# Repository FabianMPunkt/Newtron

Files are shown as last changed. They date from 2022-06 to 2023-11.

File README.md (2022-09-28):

# Newtron

This little project is made to read the USBSerial output of one these ["TesT"-devices](https://www.test-gmbh.com/de/produkte/pruefmaschinen/einfache-pruefrahmen/modell-105/).
It will process the readings, turn them all into positive values and save the highest value.

With the press of a button the highest value will the be sent to the computer using the "Keyboard.h" library.

The TesT-device trannsmits all the values over its USBSerial Port in a single line as seen in [these readings](misc/OG_readings.txt).
GitHub's formatting doen't disply this correctly though. All the values are in-fact separated by a ""

A detailed build guide & more info can be found in the [Wiki](https://github.com/FabianMPunkt/Newtron/wiki).

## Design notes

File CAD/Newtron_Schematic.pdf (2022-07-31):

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
RX1/CS1/CRX2

0
TX1/MISO1/CTX2

1
OUT2

2
LRCLK2

3
BCLK2

4
IN2

5
OUT1D

6
RX2/OUT1A

7
TX2/IN1

8
OUT1C

9
CS/MQSR 10
MOSI/CTX1 11
MISO/MQSL 12 | SCK | 13 A0/TX3/S/PDIF OUT | 14 A1/RX3/S/PDIF IN | 15 A2/RX4/SCL1 | 16 A3/TX4/SDA1 | 17 A4/SDA | 18 A5/SCL | 19 A6/TX5/LRCLK1 | 20 A7/RX5/BCLK1 | 21 A8/CTX1 | 22 A9/CRX1/MCLK1 | 23

A10/TX6/SCL2 24
A11/RX6/SDA2 25
A12/MOSI1 26
A13/SCK1 27
RX7 28
TX7 29
CRX3 30
CTX3 31
OUT1B 32 | MCLK2 | 33 RX8 | 34 TX8 | 35 CS | 36 CS | 37 A14/CS1/IN1 | 38 A15/MISO1/OUT1A | 39 A16 | 40 A17 | 41 GND | G_4 3.3V 3V_0
3.3V | 3V_1 GND | G_5 Vin | 5V GND G_2
GND | G_3 R- | RX_N R+ | RX_P T- TX_N
T+ TX_P
LED LED | GND G_1 GND G_0 | USB_D⁻ D⁻ USB_D⁺ D⁺ GND G Vhost Vhost 3.3V 3V VBAT VBAT PROGRAM P ON/OFF O | USB_IN_D⁺ IN_D⁺ USB_IN_D⁻ IN_D-

U1
Teensy 4.1

Vcc

1

GND

2

SCL

3

SDA

4 5 5 6 6 7 7 8 8 9 9 10 10 11 11 12 12 13 13 14 14 15 15 16 16 17 17 18 18 19 19 20 20 21 21 22 22 23 23 24 24 25 25 26 26 27 27 28 28 29 29 30 30 31 31 32 32 33 33 34 34 35 35 36 36

# DISPLAY LCD 1602

LCD 1602 WITH I2C 1 3 2 4

SW1

Button | VCC VCC D⁻ D⁻ D⁺ D⁺ GND GND

X1
USB A Female 231

J1
3.5mm Jack

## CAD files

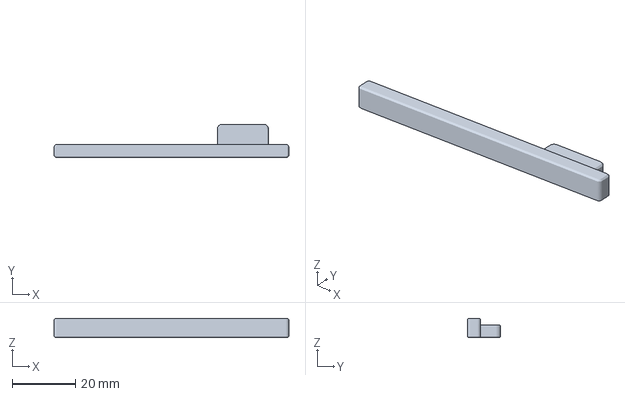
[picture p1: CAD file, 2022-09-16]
CAD/3MF/Newtron_Foot.3mf
74.2 x 10.6 x 6.06 mm

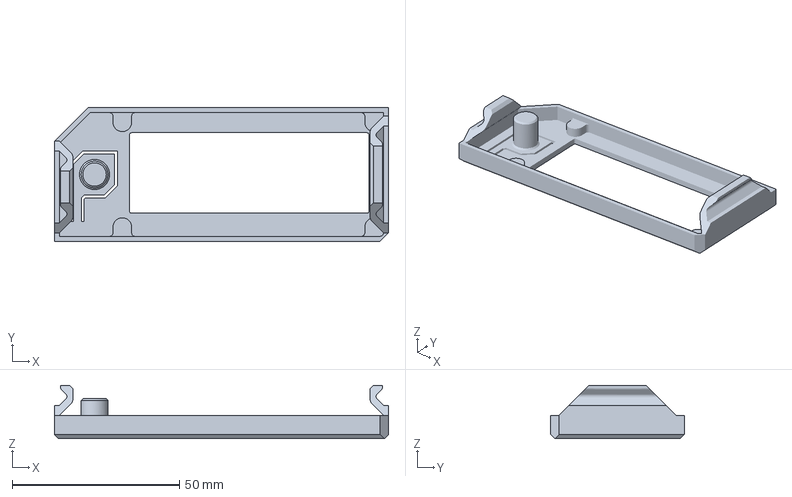
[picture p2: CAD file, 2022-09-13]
CAD/3MF/Newtron_Front.3mf
100.0 x 40.0 x 16.0 mm

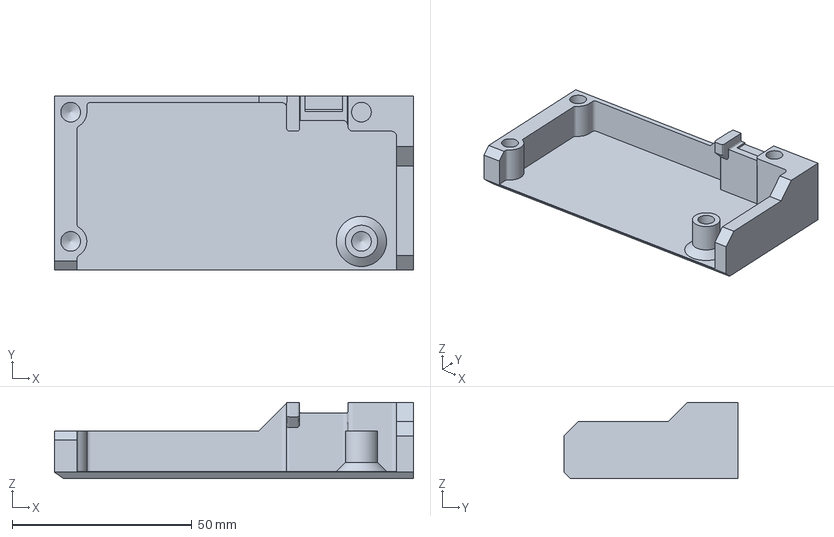
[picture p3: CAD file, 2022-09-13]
CAD/3MF/Newtron_Top.3mf
100.0 x 48.5 x 21.2 mm

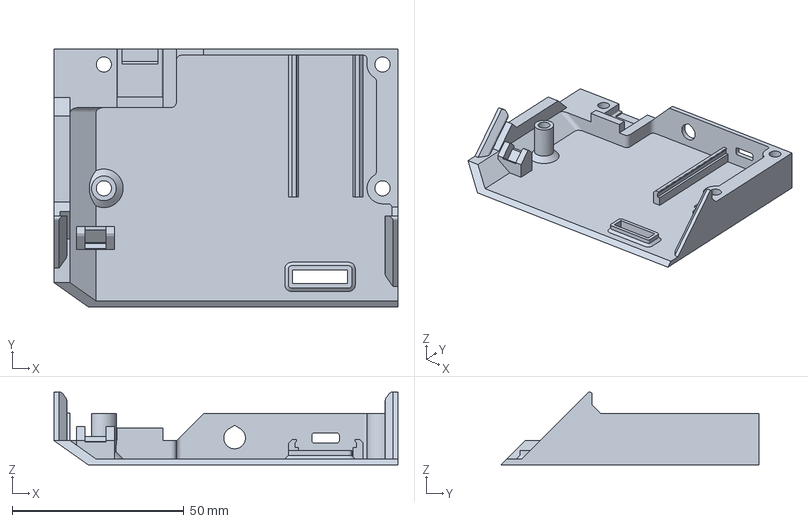
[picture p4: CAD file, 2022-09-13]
CAD/3MF/Newtron_Base.3mf
100.0 x 75.0 x 21.2 mm

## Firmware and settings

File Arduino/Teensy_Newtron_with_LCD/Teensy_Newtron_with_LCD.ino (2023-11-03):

String Version = "Newtron V1.21";

//  Teensy 4.1 + I2C LCD
//  https://github.com/FabianMPunkt/Newtron
//
//
//  USB Type: "Serial + Keyboard + Mouse + Joystick"
//  CPU Speed: 396MHz
//
//
//  This reads incoming data from Serial1, that is seperated by a "".
//  it then determines the maximum value
//  when pin3 is pulled low, it sends said value to the connected computer as if it were keyboard presses.


// Update 03.11.2023: 
// inside USBHost_t36/serial.cpp change

// // Lets try to map CDCACM devices only at device level
//  	if ((dev->bDeviceClass == 2) && (dev->bDeviceSubClass == 0)) {
//  		if (type != 0) return false;

// to

// 	// Lets try to map CDCACM devices only at device level
//	if ((dev->bDeviceClass == 2) && (dev->bDeviceSubClass == 0)) {
//
// this way it will work with newer USB-C TesT-devices.
// https://forum.pjrc.com/threads/73829-Need-help-with-USBSerial-device-not-getting-recognized-by-teensy-4-1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
//
// You may also have to uncomment "//USBHS_PORTSC1 |= USBHS_PORTSC_PFSC; // force 12 Mbit/sec"
// inside of USBHost_t36/ehci.cpp


#include "LCD_I2C.h"
LCD_I2C lcd(0x27, 16, 2);  //Defines LCD Type

#include "Keyboard.h"

#include "USBHost_t36.h"
#define USBBAUD 115200  //BAUDRADE for the Serial of the USB-Host
uint32_t baud = USBBAUD;
USBHost myusb;
USBSerial_BigBuffer userial(myusb);

USBDriver *drivers[] = { &userial };
#define CNT_DEVICES (sizeof(drivers) / sizeof(drivers[0]))
bool driver_active[CNT_DEVICES] = { false };



String integString;  //innteger part of the value
String decimString;  //decimal part of the value

float integFloat;
float decimFloat;

float finValue;
float maxValue = 0;

unsigned long millisUntilDisplayTimeout;
unsigned long displayTimeoutValue = 90000;  //timeout Value for the LCD, when inactive to prevent LCD burn-in. (using millis)

unsigned long millisUntilDataTimeout;
unsigned long dataTimeoutValue = 2000;  //timeout Value for datastream detection.

bool dataState = false;  //true if data is detected, false if not.
bool USBState = false;   //true if usb is connected, fasle if not.

const int rstPin = 11;
const int pedalPin = 8;
bool currentPedalState;
bool lastPedalState;

int animDelay = 20;

void setup() {

  bootAnimStart();  //Start sequence of the boot animation


  pinMode(pedalPin, INPUT_PULLUP);
  pinMode(rstPin, INPUT_PULLUP);

  pinMode(7, OUTPUT);  //Pin 7 and 10 are used as GND
  pinMode(10, OUTPUT);
  digitalWrite(7, LOW);
  digitalWrite(10, LOW);


  Keyboard.begin();

  Serial.begin(9600);

  Serial.println(Version);
  Serial.println("https://github.com/FabianMPunkt/Newtron");

  myusb.begin();


  bootAnimEnd();  //End sequence of the boot animation

  lcd.setCursor(0, 0);
  lcd.print("USB disconnected");  //"USB not found" message is hardcoded so it display correctly, if USB is disconnected when booting. Yes, i know it is stupid
}



void loop() {

  for (uint8_t i = 0; i < CNT_DEVICES; i++) {  //USB detection ripped from: https://github.com/PaulStoffregen/USBHost_t36/blob/master/examples/Serial/Serial.ino
    if (*drivers[i] != driver_active[i]) {

      if (driver_active[i]) {
        driver_active[i] = false;
        USBState = false;
        Serial.println("USB disconnected");
        rstMaxValue();
        lcd.clear();
        lcd.setCursor(0, 0);
        lcd.print("USB disconnected");

      }

      else {
        driver_active[i] = true;
        userial.begin(baud);
        USBState = true;
        Serial.println("USB connected");

        lcd.clear();
        rstMaxValue();

        dataState = 0;
      }
    }
  }


  while (userial.available()) {

    millisUntilDataTimeout = millis() + dataTimeoutValue;  //for datastream detection.

    if (dataState == false) {  //detects when data is coming, and runs this only once.
      lcd.setCursor(0, 0);
      lcd.print("Spitzenwert:    ");
      lcd.setCursor(0, 1);

      dataState = true;
      Serial.println("Datastream detected!");

      rstMaxValue();
    }

    integString = userial.readStringUntil(',');  //reads the value before the comma.
    integFloat = integString.toFloat();          //converts String type to Float type
    integFloat = fabsf(integFloat);              //turns all negative numbers positive


    decimString = userial.readStringUntil('');  //reads the value after the comma, until the separator ""
    decimFloat = decimString.toFloat();          //converts String type to Float type. the decimal number is now a standalone float variable.
    decimFloat = decimFloat / 10;                //devides the decimal number by 10.


    finValue = integFloat + decimFloat;  //adds integer number and decimal number.

    if (finValue > maxValue) {  //largest value gets saves as "maxValue".
      maxValue = finValue;
      displayON();  //whenever there is a new "maxValue" the LCD will turn on again.
      lcd.setCursor(0, 1);
      lcd.print(maxValue);
    }


    //    lcd.setCursor(8, 1);
    //    lcd.print("      ");
    //    lcd.setCursor(8, 1);
    //    lcd.print(finValue);


    Serial.print("fin: ");
    Serial.print(finValue);
    Serial.print(" | max: ");
    Serial.print(maxValue);
    Serial.print(" | time: ");
    Serial.print((millisUntilDisplayTimeout - millis()) / 1000);
    Serial.print(" | userial: ");
    Serial.print(userial.available());
    Serial.println();


    rstButton();

    Pedal();

    displayTimeout();
  }

  dataStreamTimeout();

  rstButton();

  displayTimeout();
}


void rstButton() {
  if (digitalRead(rstPin) == LOW) {  //reset "maxValue"
    rstMaxValue();
  }
}


void Pedal() {

  lastPedalState = currentPedalState;  //this is used to determine the falling edge when the pedal is pressed.
  currentPedalState = digitalRead(pedalPin);

  if (lastPedalState == HIGH && currentPedalState == LOW) {

    Serial.println("Pedal has been pressed");

    Keyboard.println(maxValue);
    rstMaxValue();
    delay(500);  //500ms delay so you cant accidentally press the pedal twice.
  }
}


void rstMaxValue() {
  displayON();
  maxValue = 0;
  lcd.setCursor(0, 1);
  lcd.print("                ");
  Serial.println("maxVaule has been reset");
}


void displayON() {
  millisUntilDisplayTimeout = millis() + displayTimeoutValue;

  lcd.backlight();
  lcd.display();
}


void displayTimeout() {

  if (millis() > millisUntilDisplayTimeout) {  //this turns off the LCD when the timeout is reached.
    lcd.noBacklight();
    lcd.noDisplay();
  }
}


void dataStreamTimeout() {  //if no data is coming for more than 2000ms, it will show this error.
  if (millis() > millisUntilDataTimeout) {

    if (USBState == true) {

      lcd.setCursor(0, 0);
      lcd.print("No data found!");
      lcd.setCursor(0, 1);
      lcd.print("DSI Transmission");
      dataState = false;
      Serial.println("No data found!");
    }
  }
}


void bootAnimStart() {  //fancy boot animation cus why not

  lcd.begin();
  displayON();

  lcd.setCursor(0, 0);
  lcd.print(Version.substring(0, 1));
  delay(animDelay);
  lcd.setCursor(1, 0);
  lcd.print(Version.substring(1, 2));
  delay(animDelay);
  lcd.setCursor(2, 0);
  lcd.print(Version.substring(2, 3));
  delay(animDelay);
  lcd.setCursor(3, 0);
  lcd.print(Version.substring(3, 4));
  delay(animDelay);
  lcd.setCursor(4, 0);
  lcd.print(Version.substring(4, 5));
  delay(animDelay);
  lcd.setCursor(5, 0);
  lcd.print(Version.substring(5, 6));
  delay(animDelay);
  lcd.setCursor(6, 0);
  lcd.print(Version.substring(6, 7));
  delay(animDelay);
  lcd.setCursor(7, 0);
  lcd.print(Version.substring(7, 8));
  delay(animDelay);
  lcd.setCursor(8, 0);
  lcd.print(Version.substring(8, 9));
  delay(animDelay);
  lcd.setCursor(9, 0);
  lcd.print(Version.substring(9, 10));
  delay(animDelay);
  lcd.setCursor(10, 0);
  lcd.print(Version.substring(10, 11));
  delay(animDelay);
  lcd.setCursor(11, 0);
  lcd.print(Version.substring(11, 12));
  delay(animDelay);
  lcd.setCursor(12, 0);
  lcd.print(Version.substring(12, 13));
  delay(animDelay);
}

void bootAnimEnd() {

  lcd.setCursor(0, 0);
  lcd.print("  ");
  delay(animDelay);
  lcd.print("  ");
  delay(animDelay);
  lcd.print("  ");
  delay(animDelay);
  lcd.print("  ");
  delay(animDelay);
  lcd.print("  ");
  delay(animDelay);
  lcd.print("  ");
  delay(animDelay);
}

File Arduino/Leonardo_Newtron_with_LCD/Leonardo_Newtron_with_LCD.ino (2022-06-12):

//holy shit this is working!!!!
//
//  Newtron V0.9
//  Arduino Leonardo + LCD
//  https://github.com/FabianMPunkt/Newtron
//
//
//  This reads incoming data from Serial1, that is seperated by a "".
//  it then determines the maximum value
//  when pin3 is pulled low, it sends said value to the connected computer as if it were keyboard presses.


#include <Keyboard.h>

#include <LiquidCrystal.h>

LiquidCrystal lcd(7, 8, 9, 10, 11, 12);

String integString;           //innteger part of the value
String decimString;           //decimal point of the value

float integFloat;
float decimFloat;

float finValue;
float maxValue = 0;

unsigned long currentMillis;
unsigned long millisUntilTimeout;
unsigned long timeoutValue = 30000;         //timeout Value for the LCD, when inactive to prevent LCD burn-in. (using millis)

const int lcdPowerPin = 6;
const int rstPin = 2;
const int pedalPin = 3;
const int USBStatusPin = 4;                 //Connected to pin "SS" on USB Host
bool currentPedalState;
bool lastPedalState;
bool lcdStatus;
bool lastUSBStatus = 0;
bool USBStatus;

bool USBFlag1;
bool USBFlag2;

void setup() {

  pinMode (pedalPin, INPUT_PULLUP);
  pinMode (rstPin, INPUT_PULLUP);
  pinMode (lcdPowerPin, OUTPUT);
  pinMode (USBStatusPin, INPUT);

  Keyboard.begin();

  bootAnim();                               //run this before the Serial begin stuff or things will get fucked.

  Serial.begin(9600);                       //Serial goes to the Computer
  Serial1.begin(9600);                      //Serial1 goes to the Host Controller.

  lcd.setCursor(0, 0);
  lcd.print("Spitzenwert:");
  displayON();                              //the "displayON" function will turn on the LCD and reset the timeout.

  maxValue = 0;
}

void loop() {

  currentMillis = millis();

  if (((millisUntilTimeout - currentMillis) / 1000) <= 9 ) {              //when the timeout is only 9 seconds away, it will show a countdown on the top right.
    lcd.setCursor(15, 0);
    lcd.print((millisUntilTimeout - currentMillis) / 1000);
  }


  if ((currentMillis > millisUntilTimeout) && lcdStatus == true) {        //this turns off the LCD when the timeout is reached.
    displayOFF();
  }


  USBStatus = digitalRead(USBStatusPin);


  if (USBStatus == HIGH) {                //detects rising edge of USBStatusPin, and clears the screen.
    if (USBFlag1 == LOW) {

      USBFlag1 = 1;

      Serial.println("USB connected");
      displayON();

      lcd.setCursor(0, 1);
      lcd.print("                ");

      lcd.setCursor(0, 1);
      lcd.print(maxValue);
    }
  }

  else {
    USBFlag1 = 0;
  }


  if (USBStatus == LOW) {                  //detects falling edge of USBStatusPin, and clears the screen.
    if (USBFlag2 == LOW) {

      USBFlag2 = 1;

      Serial.println("USB disconnected");
      rstMaxValue();

      lcd.setCursor(0, 1);
      lcd.print("USB disconnected");

    }
  }

  else {
    USBFlag2 = 0;
  }


  if (USBStatus) {

    integString = Serial1.readStringUntil(',');       //reads the value before the comma.
    integFloat = integString.toFloat();               //converts String type to Float type
    integFloat = fabsf(integFloat);                   //turns all negative numbers positive


    decimString = Serial1.readStringUntil('');       //reads the value after the comma, until the separator ""
    decimFloat = decimString.toFloat();               //converts String type to Float type. the decimal number is now a standalone float variable.
    decimFloat = decimFloat / 10;                     //devides the decimal number by 10.


    finValue = integFloat + decimFloat;               //adds integer number and decimal number.

    if (finValue >= maxValue) {                       //largest value gets saves as "maxValue".
      maxValue = finValue;
      displayON();                                    //whenever there is a new "maxValue" the LCD will turn on again.
      lcd.setCursor(0, 1);
      lcd.print("      ");
      lcd.setCursor(0, 1);
      lcd.print(maxValue);
    }


    lcd.setCursor(8, 1);
    lcd.print("      ");
    lcd.setCursor(8, 1);
    lcd.print(finValue);


    Serial.print("raw: ");
    Serial.print(integString);
    Serial.print(",");
    Serial.print(decimString);
    Serial.print(" | fin: ");
    Serial.print(finValue);
    Serial.print(" | max: ");
    Serial.print(maxValue);
    Serial.println();
  }


  Pedal();


  if (digitalRead(rstPin) == LOW) {           //reset "maxValue"
    rstMaxValue();
  }
}

void Pedal() {

  lastPedalState = currentPedalState;         //this is used to determine the falling edge when the pedal is pressed.
  currentPedalState = digitalRead(pedalPin);

  if (lastPedalState == HIGH && currentPedalState == LOW) {

    Serial.println("Pedal has been pressed");

    Keyboard.println(maxValue);
    rstMaxValue();
    delay(300);                             //300ms delay so you cant accidentally press the pedal twice.
  }
}


void rstMaxValue() {
  displayON();
  maxValue = 0;
  lcd.setCursor(0, 1);
  lcd.print("      ");
  Serial.println("maxVaule has been reset");
}


void displayON() {
  millisUntilTimeout = currentMillis + timeoutValue;
  digitalWrite(lcdPowerPin, HIGH);
  lcd.display();
  lcdStatus = true;

  lcd.setCursor(15, 0);
  lcd.print(" ");
}


void displayOFF() {
  lcd.noDisplay();
  digitalWrite(lcdPowerPin, LOW);
  lcdStatus = false;
}

void bootAnim() {                 //fancy boot animation cus why not
  int animDelay = 30;


  digitalWrite(lcdPowerPin, HIGH);
  lcd.begin(16, 2);

  lcd.setCursor(0, 0);
  lcd.print("N");
  delay(animDelay);
  lcd.setCursor(1, 0);
  lcd.print("e");
  delay(animDelay);
  lcd.setCursor(2, 0);
  lcd.print("w");
  delay(animDelay);
  lcd.setCursor(3, 0);
  lcd.print("t");
  delay(animDelay);
  lcd.setCursor(4, 0);
  lcd.print("r");
  delay(animDelay);
  lcd.setCursor(5, 0);
  lcd.print("o");
  delay(animDelay);
  lcd.setCursor(6, 0);
  lcd.print("n");
  delay(animDelay);
  lcd.setCursor(7, 0);
  lcd.print(" ");
  delay(animDelay);
  lcd.setCursor(8, 0);
  lcd.print("V");
  delay(animDelay);
  lcd.setCursor(9, 0);
  lcd.print("0");
  delay(animDelay);
  lcd.setCursor(10, 0);
  lcd.print(".");
  delay(animDelay);
  lcd.setCursor(11, 0);
  lcd.print("9");
  delay(1000);

  lcd.setCursor(0, 0);
  lcd.print("  ");
  delay(animDelay);
  lcd.print("  ");
  delay(animDelay);
  lcd.print("  ");
  delay(animDelay);
  lcd.print("  ");
  delay(animDelay);
  lcd.print("  ");
  delay(animDelay);
  lcd.print("  ");

  delay(300);
}

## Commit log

2022-04-28 switched to float instead of int
2022-04-28 switched to float
2022-07-02 Added 3D-files
    [Newtron_Base.3mf, Newtron_Front.3mf, Newtron_Top.3mf]
2022-07-02 changed folder name
    [Newtron_Base.3mf, Newtron_Front.3mf, Newtron_Top.3mf]
2022-07-03 edited screw-holes
    [Newtron_Base.3mf, Newtron_Top.3mf]
2022-07-27 Updated Model
    [Newtron_Base.3mf, Newtron_Front.3mf, Newtron_Top.3mf]
2022-07-29 Updated mesh files
    [Newtron_Base.3mf, Newtron_Front.3mf, Newtron_Top.3mf]
2022-07-31 Updaded Models
    [Newtron_Base.3mf, Newtron_Front.3mf, Newtron_Top.3mf]
2022-08-05 Updated Printable files
    [Newtron_Base.3mf, Newtron_Front.3mf, Newtron_Top.3mf]
2022-09-11 Updated printable parts
    [Newtron_Base.3mf, Newtron_Front.3mf, Newtron_Top.3mf]
2022-09-13 Updated printable models
    [Newtron_Base.3mf, Newtron_Foot.3mf, Newtron_Front.3mf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]
2023-11-03 Added hacky solution for newer USB-C models
    see https://forum.pjrc.com/threads/73829-Need-help-with-USBSerial-device-not-getting-recognized-by-teensy-4-1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
    Still not working on some Teensys for some reason
    [Teensy_Newtron_with_LCD.ino]
2023-11-03 Update Teensy_Newtron_with_LCD.ino
    USB-Code should now work with newer and older "TesT" devices.
